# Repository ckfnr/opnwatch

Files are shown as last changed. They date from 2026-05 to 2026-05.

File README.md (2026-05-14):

# opnwatch

**opnwatch** is an open-source wristwatch based on the ATmega328P microcontroller.

### Revision 2 of the PCB

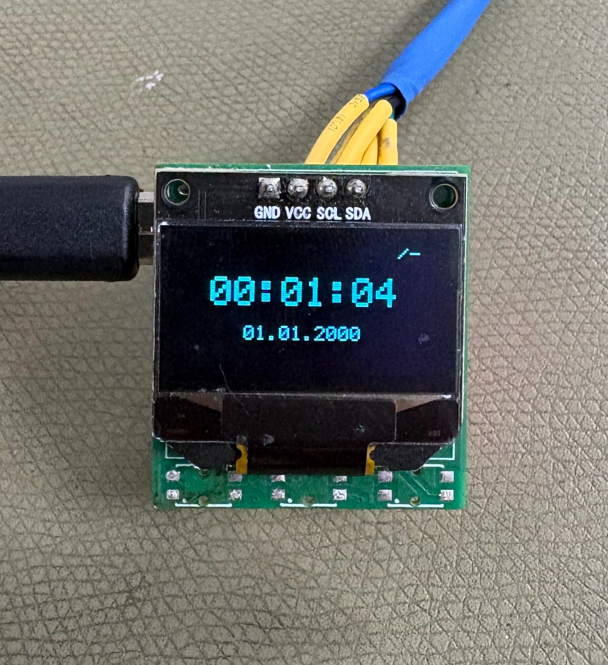
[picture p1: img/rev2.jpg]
Revision 2 of the PCB


### Revision 1 of the PCB

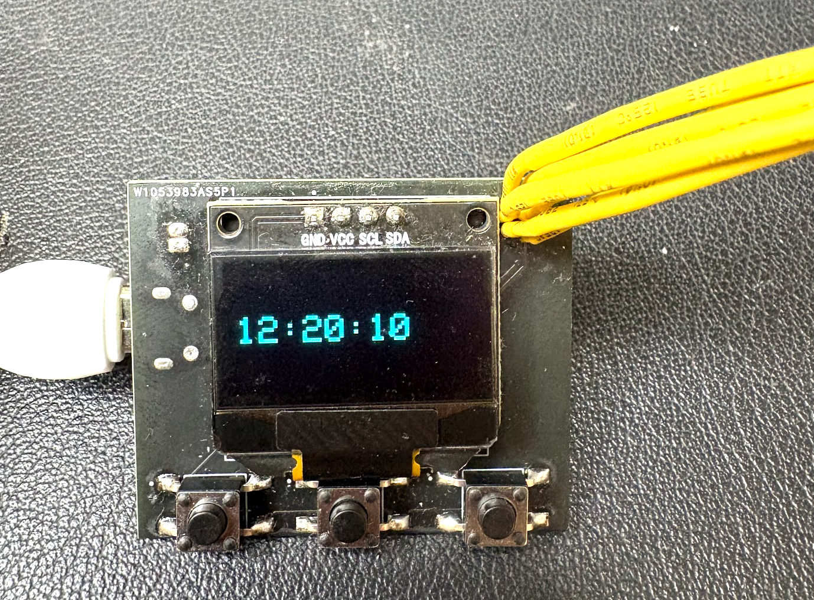
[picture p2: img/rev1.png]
Revision 1 of the PCB


## Hardware

| Component | Part |
|---|---|
| Microcontroller | ATmega328P |
| Display | SSD1306 OLED |
| RTC | DS3231M |
| Charging IC | BQ24075RGT |
| PCB | Custom, designed in KiCad |

## Repository Structure

```
opnwatch/
├── CAD_files/        # KiCad schematic and PCB layout
    ├── rev2                # Revision 2 of the PCB
    └── rev3                # Revision 3 of the PCB
├── img/              # PCB and design images
└── watch_firmware/   # AVR-GCC firmware
    └── lib/
        └── oled-display/   # Vendored OLED library
```

## License

This project is open source. See [LICENSE](LICENSE) for details.

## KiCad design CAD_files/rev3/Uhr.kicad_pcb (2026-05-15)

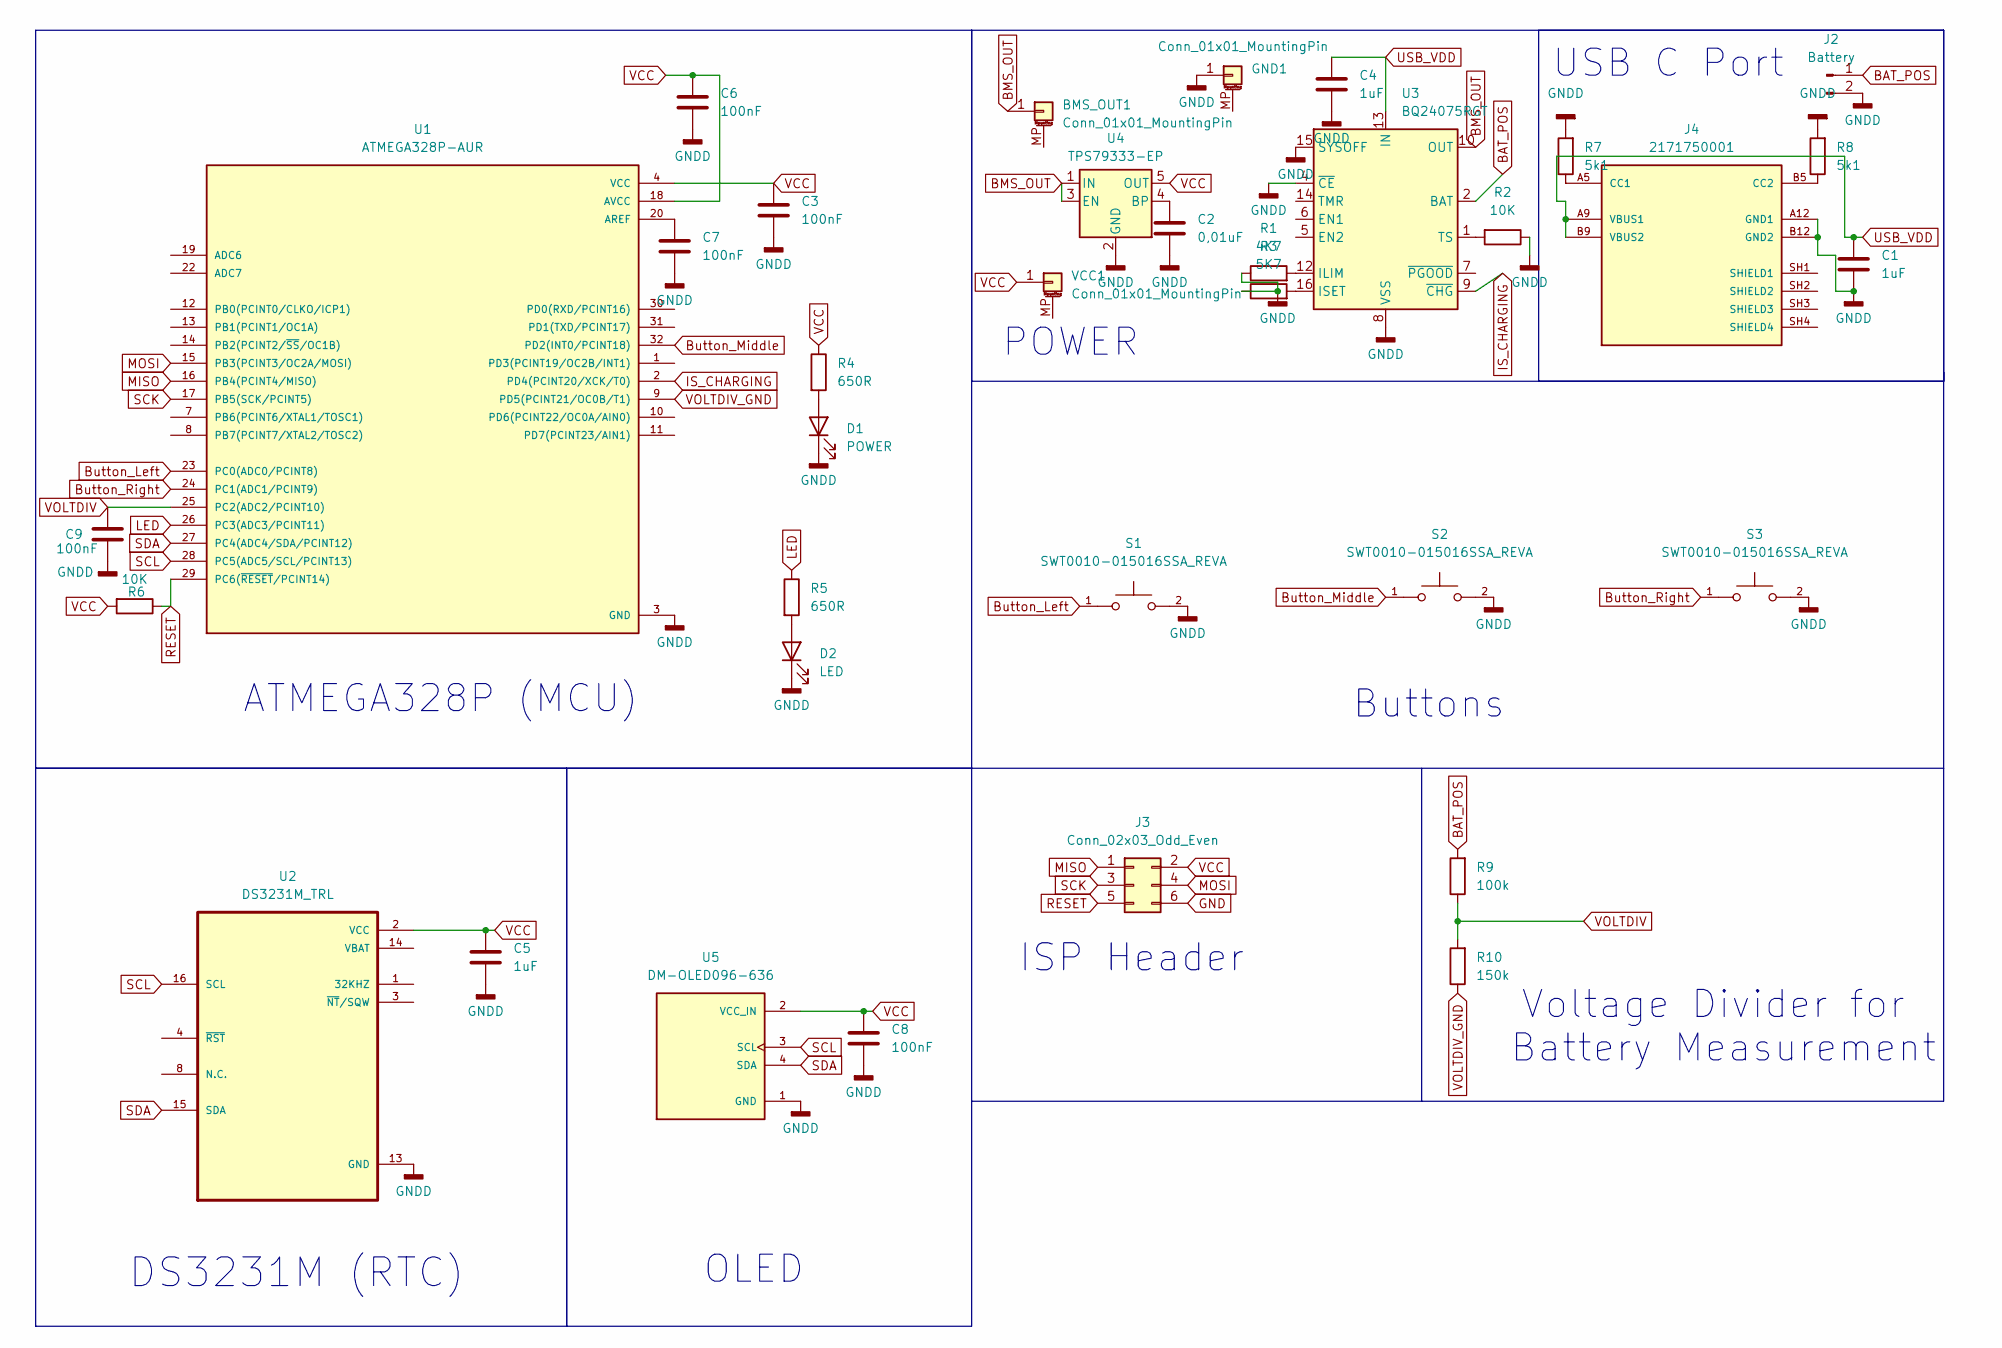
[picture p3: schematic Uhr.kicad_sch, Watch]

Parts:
BMS_OUT1: Conn_01x01_MountingPin; TestPoint_Pad_D1.5mm
C1, C4, C5: 1uF; C_0603_1608Metric
C2: 0,01uF; C_0603_1608Metric
C3: 100nF; C_0603_1608Metric_Pad1.08x0.95mm_HandSolder
C6, C7, C8, C9: 100nF; C_0603_1608Metric
D1: POWER; LED_0603_1608Metric
D2: LED; LED_0603_1608Metric
GND1: Conn_01x01_MountingPin; TestPoint_Pad_D1.5mm
J2: Battery; Wuerth_WR-WTB_64800211622_1x02_P1.50mm_Vertical
J3: Conn_02x03_Odd_Even; PinHeader_2x03_P1.00mm_Vertical
J4: 2171750001; MOLEX_2171750001; PARTREV A1
R1: 4K7; R_0603_1608Metric
R2, R6: 10K; R_0603_1608Metric
R3: 5K7; R_0603_1608Metric
R4, R5: 650R; R_0603_1608Metric
R7, R8: 5k1; R_0603_1608Metric
R9: 100k; R_0603_1608Metric
R10: 150k; R_0603_1608Metric
S1, S2, S3: SWT0010-015016SSA_REVA; SW_SWT0010-015016SSA_REVA; PARTREV A
U1: ATMEGA328P-AUR; QFP80P900X900X120-32N; PARTREV A
U2: DS3231M_TRL; SOIC127P1032X265-16N
U3: BQ24075RGT; VQFN-16-1EP_3x3mm_P0.5mm_EP1.6x1.6mm
U4: TPS79333-EP; SOT-23-5
U5: DM-OLED096-636; MODULE_DM-OLED096-636; PARTREV 2018-09-10
VCC1: Conn_01x01_MountingPin; TestPoint_Pad_D1.5mm

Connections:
BAT_POS: J2.1, R9.2, U3.2 (BAT), U3.3 (BAT)
BMS_OUT: BMS_OUT1.1 (Pin_1_1), U3.10 (OUT), U3.11 (OUT), U4.1 (IN), U4.3 (EN)
Button_Left: S1.1, U1.23 (PC0(ADC0/PCINT8))
Button_Middle: S2.1, U1.32 (PD2(INT0/PCINT18))
Button_Right: S3.1, U1.24 (PC1(ADC1/PCINT9))
IS_CHARGING: U1.2 (PD4(PCINT20/XCK/T0)), U3.9 (~CHG)
LED: R5.1, U1.26 (PC3(ADC3/PCINT11))
MISO: J3.1, U1.16 (PB4(PCINT4/MISO))
MOSI: J3.4, U1.15 (PB3(PCINT3/OC2A/MOSI))
unnamed: D1.2 (A), R4.2
unnamed: D2.2 (A), R5.2
unnamed: J4.A5 (CC1), R7.1
unnamed: J4.B5 (CC2), R8.1
unnamed: C7.1, U1.20 (AREF)
unnamed: U2.5 (N.C.), U2.6 (N.C.), U2.7 (N.C.), U2.8 (N.C.), U2.9 (N.C.), U2.10 (N.C.), U2.11 (N.C.), U2.12 (N.C.)
unnamed: R1.2, U3.12 (ILIM)
unnamed: R3.2, U3.16 (ISET)
unnamed: R2.2, U3.1 (TS)
unnamed: C2.1, U4.4 (BP)
RESET: J3.5, R6.1, U1.29 (PC6(~RESET/PCINT14))
SCK: J3.3, U1.17 (PB5(SCK/PCINT5))
SCL: U1.28 (PC5(ADC5/SCL/PCINT13)), U2.16 (SCL), U5.3 (SCL)
SDA: U1.27 (PC4(ADC4/SDA/PCINT12)), U2.15 (SDA), U5.4 (SDA)
USB_VDD: C1.1, C4.1, J4.A9 (VBUS1), J4.B9 (VBUS2), U3.13 (IN)
VCC: C3.2, C5.1, C6.1, C8.1, J3.2, R4.1, R6.2, U1.4 (VCC), U1.6 (VCC), U1.18 (AVCC), U2.2 (VCC), U4.5 (OUT), U5.2 (VCC_IN), VCC1.1 (Pin_1_1)
VOLTDIV: C9.1, R9.1, R10.2, U1.25 (PC2(ADC2/PCINT10))
VOLTDIV_GND: R10.1, U1.9 (PD5(PCINT21/OC0B/T1))

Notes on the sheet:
Buttons
Voltage Divider for Battery Measurement
USB C Port
POWER
OLED
ISP Header
ATMEGA328P (MCU)
DS3231M (RTC)

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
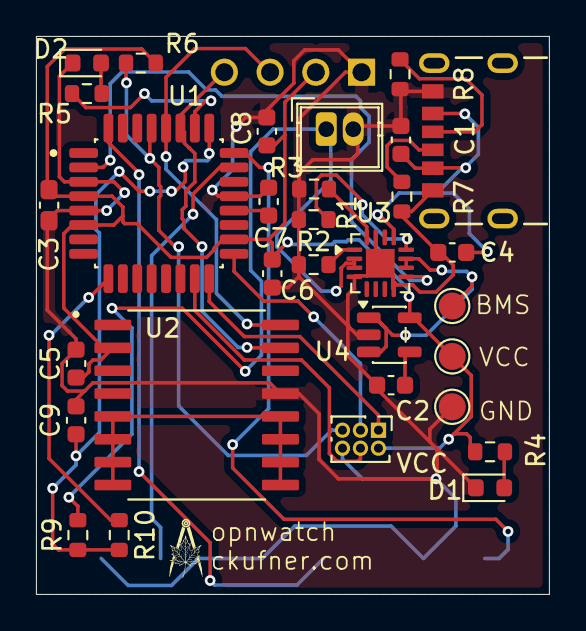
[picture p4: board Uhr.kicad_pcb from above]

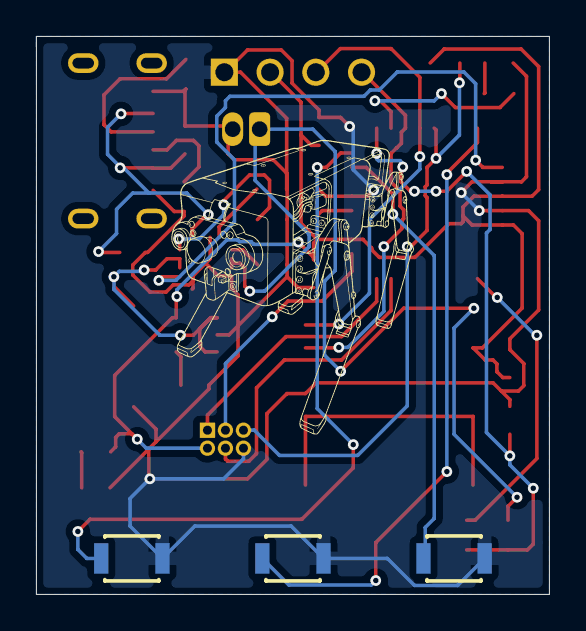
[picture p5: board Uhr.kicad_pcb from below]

Board: 2 copper layers, 28.5 x 31.0 mm, 35 parts (4 on the bottom side), 28 nets.

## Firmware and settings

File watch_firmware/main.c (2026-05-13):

#include <avr/io.h>
#include <util/delay.h>
#include <stdio.h>
#include <string.h>
#include "lib/oled-display/lcd.h"
#include "lib/oled-display/i2c.h"
#include "ds3231.h"

// ================== PINS ==================
#define CHG_PIN    PD4
#define CHG_DDR    DDRD
#define CHG_PORT   PORTD
#define CHG_PINREG PIND

#define LED_PIN    PC3
#define LED_DDR    DDRC
#define LED_PORT   PORTC

// ================== LAYOUT ================
// Display: 128x64px, TEXTMODE
// NORMALSIZE: 1 Zeichen = 6px breit, 8px hoch → 21 Zeichen / 8 Zeilen
// DOUBLESIZE: 1 Zeichen = 12px breit, 16px hoch → 10 Zeichen / 4 Zeilen
//
// Uhrzeit (DOUBLESIZE, "HH:MM:SS" = 8 Zeichen = 96px) → x=1 für ~zentriert
// Datum   (NORMALSIZE, "DD.MM.YYYY" = 10 Zeichen = 60px) → x=5 für ~zentriert
// Blitz   (NORMALSIZE, oben rechts) → x=19, y=0

// ================== COMPILE TIME ==========
static ds3231_t compile_time(void) {
    const char *months = "JanFebMarAprMayJunJulAugSepOctNovDec";
    const char *date = __DATE__;
    const char *time = __TIME__;

    ds3231_t t;

    char mon_str[4] = {date[0], date[1], date[2], 0};
    t.month = 1;
    for (uint8_t i = 0; i < 12; i++) {
        if (months[i*3]   == mon_str[0] &&
            months[i*3+1] == mon_str[1] &&
            months[i*3+2] == mon_str[2]) {
            t.month = i + 1;
            break;
        }
    }

    t.day  = (date[4] == ' ' ? 0 : date[4] - '0') * 10 + (date[5] - '0');
    t.year = (date[7] - '0') * 1000 + (date[8] - '0') * 100
           + (date[9] - '0') * 10   + (date[10] - '0');

    t.hour = (time[0] - '0') * 10 + (time[1] - '0');
    t.min  = (time[3] - '0') * 10 + (time[4] - '0');
    t.sec  = (time[6] - '0') * 10 + (time[7] - '0');

    return t;
}

// ================== MAIN ==================
int main(void) {
    _delay_ms(1500);

    // LED: Output, aus
    LED_DDR  |=  (1 << LED_PIN);
    LED_PORT &= ~(1 << LED_PIN);

    // CHG: Input mit Pullup (active low)
    CHG_DDR  &= ~(1 << CHG_PIN);
    CHG_PORT |=  (1 << CHG_PIN);

    i2c_init();
    lcd_init(LCD_DISP_ON);

    // Einmalig Zeit setzen — danach auskommentieren und nochmal flashen
    // ds3231_t set = compile_time();
    // ds3231_set(&set);

    char time_str[9]  = {0};  // "HH:MM:SS"
    char date_str[11] = {0};  // "DD.MM.YYYY"
    char prev_time[9]  = {0};
    char prev_date[11] = {0};

    uint8_t prev_charging = 0xFF; // ungültiger Startwert → erster Draw erzwungen
    uint8_t anim_frame    = 0;
    uint8_t anim_tick     = 0;

    while (1) {
        ds3231_t t;
        ds3231_get(&t);

        uint8_t charging = !(CHG_PINREG & (1 << CHG_PIN));

        // LED
        if (charging)
            LED_PORT |=  (1 << LED_PIN);
        else
            LED_PORT &= ~(1 << LED_PIN);

        // Uhrzeit (DOUBLESIZE, zentriert)
        snprintf(time_str, sizeof(time_str), "%02d:%02d:%02d", t.hour, t.min, t.sec);
        if (memcmp(time_str, prev_time, sizeof(time_str)) != 0) {
            lcd_charMode(DOUBLESIZE);
            lcd_gotoxy(2, 2);   // y=2 → Zeile 2 (Pixel 16), zentriert vertikal oben
            lcd_puts(time_str);
            lcd_charMode(NORMALSIZE);
            memcpy(prev_time, time_str, sizeof(time_str));
        }

        // Datum (NORMALSIZE, zentriert)
        snprintf(date_str, sizeof(date_str), "%02d.%02d.%04d", t.day, t.month, t.year);
        if (memcmp(date_str, prev_date, sizeof(date_str)) != 0) {
            lcd_charMode(NORMALSIZE);
            lcd_gotoxy(5, 5);   // y=5 → unter der Uhrzeit
            lcd_puts(date_str);
            memcpy(prev_date, date_str, sizeof(date_str));
        }

        // Charging-Anzeige oben rechts
        if (charging != prev_charging || charging) {
            lcd_charMode(NORMALSIZE);

            if (charging) {
                // Blitz-Symbol: "/-\" sieht aus wie ein Blitz in diesem Font
                const char *frames[] = {"/", "/-", "/-\\"};
                anim_tick++;
                if (anim_tick >= 3) {
                    anim_tick = 0;
                    anim_frame = (anim_frame + 1) % 4;
                }
                if (anim_frame == 3) {
                    lcd_gotoxy(18, 0);
                    lcd_puts("   ");   // löschen
                } else {
                    lcd_gotoxy(18, 0);
                    lcd_puts("   ");   // erst löschen
                    lcd_gotoxy(18, 0);
                    lcd_puts(frames[anim_frame]);
                }
            } else {
                // löschen
                lcd_gotoxy(18, 0);
                lcd_puts("   ");
                anim_frame = 0;
                anim_tick  = 0;
            }

            prev_charging = charging;
        }

        _delay_ms(100);
    }
}

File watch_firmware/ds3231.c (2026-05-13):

#include "ds3231.h"
#include "lib/oled-display/i2c.h"

#define DS3231_ADDR 0x68

static uint8_t bcd2dec(uint8_t b) { return (b >> 4) * 10 + (b & 0x0F); }
static uint8_t dec2bcd(uint8_t d) { return ((d / 10) << 4) | (d % 10); }

void ds3231_get(ds3231_t *t) {
    i2c_start(DS3231_ADDR << 1);
    i2c_byte(0x00);
    i2c_start((DS3231_ADDR << 1) | 1);
    t->sec   = bcd2dec(i2c_readAck()  & 0x7F);
    t->min   = bcd2dec(i2c_readAck());
    t->hour  = bcd2dec(i2c_readAck()  & 0x3F);
    i2c_readAck();
    t->day   = bcd2dec(i2c_readAck());
    t->month = bcd2dec(i2c_readAck()  & 0x1F);
    t->year  = bcd2dec(i2c_readNAck()) + 2000;
    i2c_stop();
}

void ds3231_set(const ds3231_t *t) {
    i2c_start(DS3231_ADDR << 1);
    i2c_byte(0x00);
    i2c_byte(dec2bcd(t->sec));
    i2c_byte(dec2bcd(t->min));
    i2c_byte(dec2bcd(t->hour));
    i2c_byte(0x01);                     // Wochentag
    i2c_byte(dec2bcd(t->day));
    i2c_byte(dec2bcd(t->month));
    i2c_byte(dec2bcd(t->year - 2000));
    i2c_stop();
}

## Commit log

2026-05-13 add oled-display lib as vendor dependency
    [Uhr.kicad_pcb, Uhr.kicad_sch]
2026-05-13 ignore KiCad history directory
2026-05-14 revision 3 of the PCB
    [Uhr.kicad_pcb, Uhr.kicad_sch]
2026-05-14 updated readme, removed backups from CAD folders
2026-05-15 removed leftover traces from rev2
    [Uhr.kicad_pcb]
